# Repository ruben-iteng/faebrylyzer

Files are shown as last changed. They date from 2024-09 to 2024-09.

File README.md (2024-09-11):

<div align="center">

# faebrylyzer

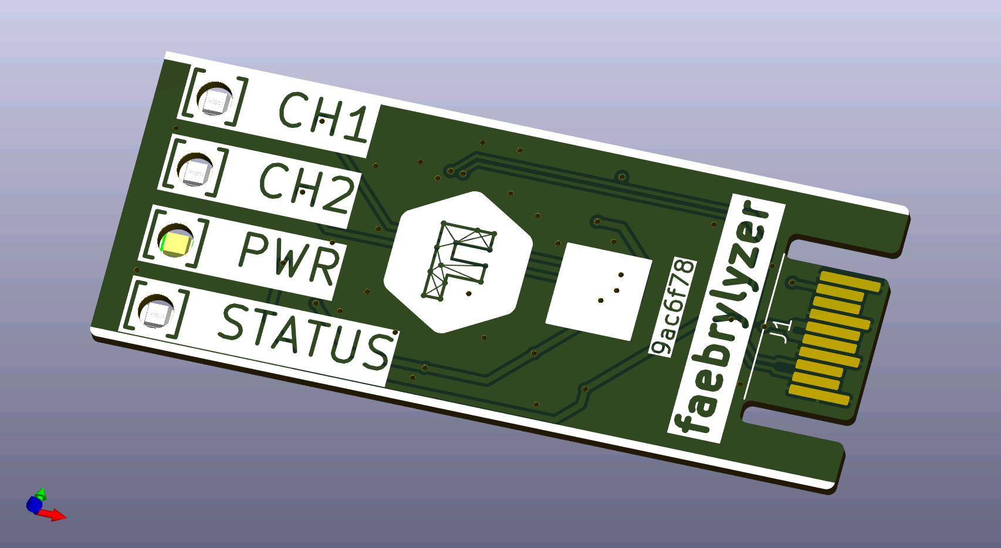
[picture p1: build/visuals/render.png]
Render

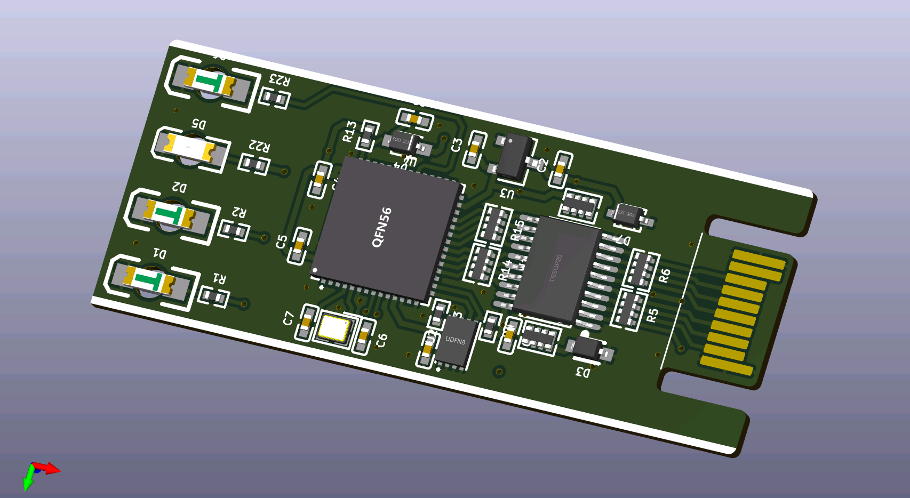
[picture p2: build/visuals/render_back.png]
Render

<br/>

8 channel logic analyser compatible with the fx2lafw firmware

     

</div>

## About

faebrylyzer is an 8 channel logic analyser compatible with the fx2lafw firmware. It is designed to be integrated as a module into other projects (e.g. a factory test rig).
This project is build with the open-source EDA [faebryk](https://github.com/faebryk/faebryk).

## Working with the source files

See [here](./docs/development.md) for the instructions on how to install and edit this project.

## Building

If you want to build the physical output of this project you can find the build instructions [here](./docs/build_instructions.md).

## Contributing

If you want to share your alterations, improvements, or add bugfixes to this project, please take a look at the [contributing guidelines](./docs/CONTRIBUTING.md).

## Community Support

Community support is provided via Discord; see the Resources below for details.

### Resources

- Source Code: [Github](https://github.com/ruben-iteng/faebrylyzer)
- Chat: Real-time chat happens in faebryk's Discord Server (chit-chat room for now). Use this Discord [Invite](https://discord.gg/95jYuPmnUW) to register
- Issues: [Issues](https://github.com/ruben-iteng/faebrylyzer/issues)

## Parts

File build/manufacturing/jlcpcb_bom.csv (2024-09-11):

Designator | Footprint | Quantity | Value | Manufacturer | Partnumber | LCSC Part #
C1, C2, C3, C4, C5, C9 | C0402 | 6 | 2.2µF ±20% 6.3V X5R | Samsung Electro-Mechanics | CL05A225MQ5NSNC | C12530
C6, C7 | C0402 | 2 | 15pF 50V C0G |  |  | C1548
C8 | C0402 | 1 | 1µF 25V X5R |  |  | C52923
D1, D2, D6 | LED-SMD_L3.2-W1.3-RD_GREEN-MHT151UGCT | 3 | 3.05V |  |  | C559120
D3 | SOD-323_L1.7-W1.3-LS2.5-BI | 1 |  |  |  | C907859
D4 | SOD-323_L1.8-W1.3-LS2.5-RD | 1 |  |  |  | C2128
D5 | LED-SMD_L3.2-W1.3-RD_MHT151WDT | 1 | 3.15V |  |  | C401114
R1, R2, R23 | R0402 | 3 | 200Ω |  |  | C25087
R3, R4, R13 | R0402 | 3 | 3.3kΩ |  |  | C25890
R5, R6, R14, R15 | RES-ARRAY-SMD_0402-8P-L2.0-W1.0-BL | 4 |  |  |  | C270393
R7, R8 | RES-ARRAY-SMD_8P-L2.0-W1.0-BL_CN24XXXX | 2 |  |  |  | C162977
R22 | R0402 | 1 | 1kΩ |  |  | C11702
U1 | TSSOP-20_L6.5-W4.4-P0.65-LS6.4-BL | 1 |  |  |  | C113281
U2 | UDFN-8_L3.0-W2.0-P0.50-TL | 1 |  |  |  | C233771
U3 | SOT-23-3_L2.9-W1.6-P1.90-LS2.8-BR | 1 | LDO 3.3V 250mA Vin max 4.75V - 5.25V Iq |  |  | C236655
U4 | QFN-56_L8.0-W8.0-P0.50-BL-EP | 1 |  |  |  | C476253
XTAL1 | CRYSTAL-SMD_4P-L3.2-W2.5-BL | 1 |  |  |  | C70590

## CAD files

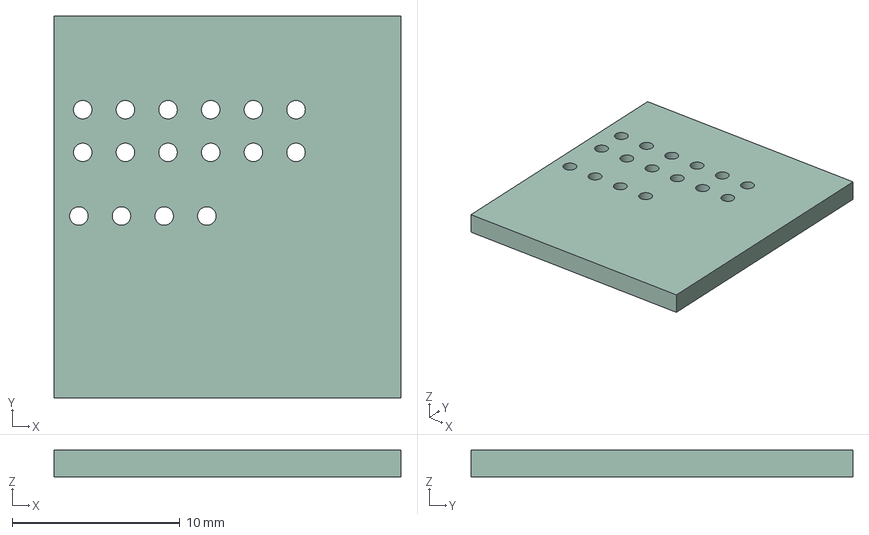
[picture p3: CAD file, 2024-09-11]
source/main.step
20.7 x 22.7 x 1.60 mm

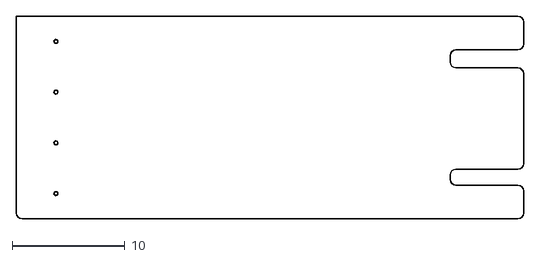
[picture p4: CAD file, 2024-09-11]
build/manufacturing/cad/pcba.dxf
45.0 x 18.0

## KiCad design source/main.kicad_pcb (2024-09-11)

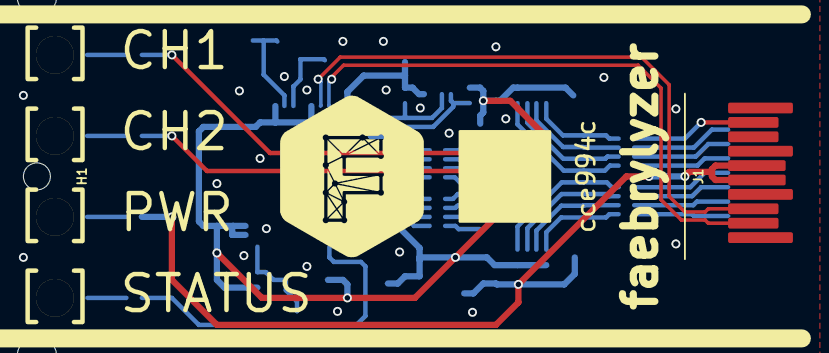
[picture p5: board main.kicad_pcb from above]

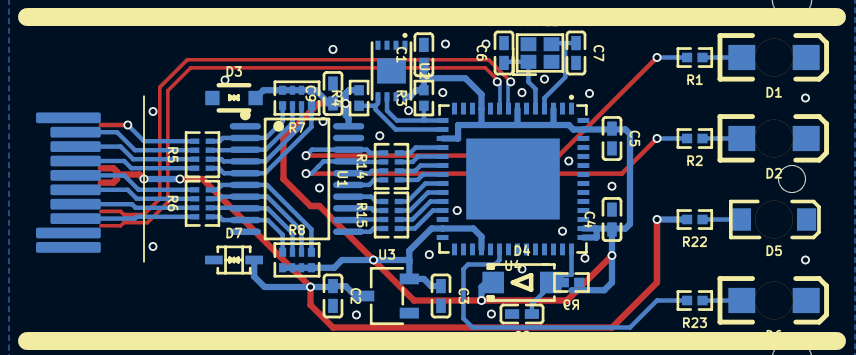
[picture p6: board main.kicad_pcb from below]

Board: 4 copper layers, 37 parts (34 on the bottom side), 47 nets.

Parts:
C1, C2, C3, C4, C5, C6, C7, C9: 15pF 50V C0G; C0402
C8: 1µF 25V X5R; C0402
D1, D2, D6: 3.05V; LED-SMD_L3.2-W1.3-RD_GREEN-MHT151UGCT
D3: SOD-323_L1.7-W1.3-LS2.5-BI
D4: 1.3V; SOD-123FL_L2.8-W1.8-LS3.7-RD
D5: 3.15V; LED-SMD_L3.2-W1.3-RD_MHT151WDT
D7: SOD-323_L1.8-W1.3-LS2.5-BI
H1: MountingSlot
J1: SFPEdgeConnector; SFP_Edge
LOGO1: faebrykLogo; faebryk_logo
R1, R2, R3, R4, R9: 100Ω; R0402
R5, R6, R14, R15: ResistorArray; RES-ARRAY-SMD_0402-8P-L2.0-W1.0-BL
R7, R8: ResistorArray; RES-ARRAY-SMD_8P-L2.0-W1.0-BL_CN24XXXX
R22: 1kΩ; R0402
R23: 200Ω; R0402
U1: SNx4LVC541A; TSSOP-20_L6.5-W4.4-P0.65-LS6.4-BL
U2: EEPROM; UDFN-8_L3.0-W2.0-P0.50-TL
U3: LDO 3.3V 237.5mA - 262.5mA Vin max 5V Iq; SOT-23-3_L2.9-W1.6-P1.90-LS2.8-BR
U4: CBM9002A_56ILG; QFN-56_L8.0-W8.0-P0.50-BL-EP
XTAL1: Crystal; CRYSTAL-SMD_4P-L2.0-W1.6-BL-A

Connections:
3v3: C1.1, C3.1, C4.1, C5.1, C9.1, D3.2, D4.1, R3.2, R4.2, R7.5, R7.6, R7.7, R7.8, R8.5, R8.6, R8.7, R8.8, R9.2, U1.20, U2.8, U3.2, U4.3, U4.7, U4.11, U4.17, U4.27, U4.32, U4.43, U4.44, U4.55
C6-1-U4-5-XTAL1-1: C6.1, U4.5, XTAL1.1
C7-1-U4-4-XTAL1-3: C7.1, U4.4, XTAL1.3
C8-1-D4-2-R9-1-U4-42: C8.1, D4.2, R9.1, U4.42
D1-2-R1-1: D1.2, R1.1
D2-2-R2-1: D2.2, R2.1
D5-2-R22-1: D5.2, R22.1
D6-2-R23-1: D6.2, R23.1
R23-2-U4-34: R23.2, U4.34
buffer_in_0: R5.5, R7.4, U1.2
buffer_in_1: R5.6, R7.3, U1.3
buffer_in_2: R5.7, R7.2, U1.4
buffer_in_3: R5.8, R7.1, U1.5
buffer_in_4: R6.5, R8.4, U1.6
buffer_in_5: R6.6, R8.3, U1.7
buffer_in_6: R6.7, R8.2, U1.8
buffer_in_7: R6.8, R8.1, U1.9
buffer_out_0: R1.2, R14.4, U1.18
buffer_out_1: R2.2, R14.3, U1.17
buffer_out_2: R14.2, U1.16
buffer_out_3: R14.1, U1.15
buffer_out_4: R15.4, U1.14
buffer_out_5: R15.3, U1.13
buffer_out_6: R15.2, U1.12
buffer_out_7: R15.1, U1.11
ch_0: J1.19, R5.4
ch_1: J1.2, R5.3
ch_2: J1.3, R5.2
ch_3: J1.4, R5.1
ch_4: J1.5, R6.4
ch_5: J1.6, R6.3
ch_6: J1.7, R6.2
ch_7: J1.8, R6.1
gnd: C1.2, C2.2, C3.2, C4.2, C5.2, C6.2, C7.2, C8.2, C9.2, D1.1, D2.1, D3.1, D5.1, D6.1, D7.1, J1.1, J1.10, J1.11, J1.14, J1.17, J1.20, U1.1, U1.10, U1.19, U2.1, U2.2, U2.3, U2.4, U2.7, U3.1, U4.6, U4.10, U4.12, U4.14, U4.26, U4.28, U4.41, U4.53, U4.56, U4.57, XTAL1.2, XTAL1.4
mcu_logic_0: R14.5, U4.18
mcu_logic_1: R14.6, U4.19
mcu_logic_2: R14.7, U4.20
mcu_logic_3: R14.8, U4.21
mcu_logic_4: R15.5, U4.22
mcu_logic_5: R15.6, U4.23
mcu_logic_6: R15.7, U4.24
mcu_logic_7: R15.8, U4.25
scl: R3.1, U2.6, U4.15
sda: R4.1, U2.5, U4.16
usb_N: J1.12, U4.9
usb_P: J1.13, U4.8
vbus: C2.1, D7.2, J1.15, J1.16, R22.2, U3.3

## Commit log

2024-08-23 initial version wip
    [main.kicad_pcb, main.kicad_sch]
2024-08-24 Add: routing and finilize placement
    [main.kicad_pcb, main.step]
2024-08-24 Add: manufacturing arifacts
    [jlcpcb_bom.csv, jlcpcb_pick_and_place.csv, main.kicad_pcb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]
2024-09-03 Update to fabll
    [main.kicad_pcb, pcba.dxf]
2024-09-11 Fix constants; Run
    [main.kicad_pcb]

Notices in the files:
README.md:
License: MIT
